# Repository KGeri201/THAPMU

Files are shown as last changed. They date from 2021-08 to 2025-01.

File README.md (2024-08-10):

<p align="center"></P>

# THAPMU
THAPMU stands for **T**emerature, **H**umiditity and **A**ir **P**ressure **M**easurement **U**nit. 

## Story
I wanted to create a small, cheap and easy to make IoT sensor, that works with nearly anything,  
to monitor the temerapture and humidity levels of multiple rooms.

## Hardware
The custom PCB is a very simple power adapter to power and connect the sensor and the ESP.

## Software
It uses [ESPHome](https://esphome.io/index.html), [MQTT](https://de.wikipedia.org/wiki/MQTT), [InfluxDB](https://www.influxdata.com/) and a [script](MQTTInfluxDBBridge.py) to connect all this together.  
I found a [code](https://randomnerdtutorials.com/esp8266-nodemcu-mqtt-publish-bme280-arduino/) very similar and nearly perfect for my use.  
I only modified it a little to make it a perfect fit.    
It uses Grafana to visualize the data, but anything else can be used.

## Installation
### Docker (recomended)
Follow the Guide for [docker deployment](DOCKER.md)

### Manual
Download the thapmu.sh with wget or any other way.
```sh
wget https://raw.githubusercontent.com/KGeri201/THAPMU/main/thapmu.sh
```
And execute it as sudo
```sh
sudo ./thapmu.sh
```
#### Step by step
Grafana will be added to apt sources.  
All the needed packages will be installed  
```sh
apt-get install -y influxdb influxdb-client mosquitto mosquitto-clients python3 python3-pip grafana-enterprise
```
All the neded files will be downloaded.
```sh
wget -q -O /tmp/requirements.txt https://raw.githubusercontent.com/KGeri201/THAPMU/main/requirements.txt
wget -q -O MQTTInfluxDBBridge.py https://raw.githubusercontent.com/KGeri201/THAPMU/main/MQTTInfluxDBBridge.py
wget -q -O /etc/systemd/system/mqttinfluxdbbridge.service https://raw.githubusercontent.com/KGeri201/THAPMU/main/mqttinfluxdbbridge.service
```
Additional config will be added to mosquitto  
```sh
echo "listener 1883" > /etc/mosquitto/conf.d/allow.conf && echo "allow_anonymous true" >> /etc/mosquitto/conf.d/allow.conf
```
Python libraries will also be installed  
```sh
pip3 -q install -r /tmp/requirements.txt
```
Database will be set up, and services will be started
```sh
systemctl start mqttinfluxdbbridge
systemctl start grafana-server
systemctl restart influxdb
systemctl start mosquitto
```
Additionaly you can also enable all the services to start automatically after starting the device  
```sh
systemctl enable mosquitto
systemctl enable influxdb
systemctl enable grafana-server
systemctl enable mqttinfluxdbbridge
```

## Sensor
### Requirements
* 1 THAPMU board (fully fitted, and ready to use)
* 1 ESP01 breakout board
* 1 BME or BMP sensor
* an extra external serial adapter to flash your ESP
* an USB-C cable to power the board.

### Instructions
#### ESPHome
1. Install ESPHome on a server.
2. Go to http://ip-of-your-server:6052
3. Add new device.
4. Load the [example_esphome.conf](example_esphome.conf) and edit the values to fit your needs.  
   Make sure that the right sensor is selected and all the credentials are right.
5. Flash the code to the ESP following the guide from ESPHome

#### Legacy
1. Open the code for the ESP and change the library according to your sensor.  
```ino
#include <Adafruit_BME280.h>

// Sensor I2C
Adafruit_BME280 sensor;
```
2. Fill in your WLAN SSID and password, and the address of the MQTT broker.  
   If your MQTT broker needs credentials to authenticate, set them.  
   Also add the location and the name of the device.
```ino
#define NAME "NAME_OF_THE_DEVICE"
#define LOCATION "LOCATION_OF_THE_DEVICE"
#define WIFI_SSID "REPLACE_WITH_YOUR_SSID"
#define WIFI_PASSWORD "REPLACE_WITH_YOUR_PASSWORD"

// Raspberri Pi Mosquitto MQTT Broker
#define MQTT_HOST IPAddress(X, X, X, X)
// For a cloud MQTT broker, type the domain name
//#define MQTT_HOST "example.com"
#define MQTT_PORT 1883
// If your MQTT broker requires authentication, set them below
#define MQTT_USER ""
#define MQTT_PASSWORD ""
``` 
3. Flash the ESP.  
4. Plug the board in somewhere and wait for it to connect to your WLAN and to the Server, which you previously set up (decribed under [Installation](https://github.com/KGeri201/THAPMU#installation)).
5. Go to the [Grafana](https://grafana.com/) site, hosted on your server http://ip-of-your-server:3000 and login with the default credentials.
6. Under the Configurations add the [InfluxDB](https://www.influxdata.com/products/influxdb-overview/) data source.  
  Fill in the name of the database, user and password.  
  These you have set during the setup process.
7. Make a new dashboard with the newly added InfluxDB datasource and choose the measurement.  
There are three topics:  
   - THAPMU/**LOCATION**/**NAME**/sensor/temperature/state   
   - THAPMU/**LOCATION**/**NAME**/sensor/humidity/state
   - THAPMU/**LOCATION**/**NAME**/sensor/pressure/state
8. You are up and running.  

## Credits
[HimbeersaftLP](https://github.com/HimbeersaftLP)  
[KGeri201](https://github.com/KGeri201)  

## License
[Apache License 2.0](LICENSE)

## Project status
Ready to deploy.

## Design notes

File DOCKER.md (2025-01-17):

# THAPMU

Guide to deploy project as a docker container.  
To run the container, MQTT and InfluxDB are required.
To visuallize the data we use grafana.

## Docker Compose
```yml
version: '3.3'
services:
  mqtt:
    container_name: mosquitto
    restart: unless-stopped
    ports:
      - 1883:1883
    volumes:
      - ./mosquitto:/mosquitto/config
    image: eclipse-mosquitto:latest

  db:
    container_name: influxdb
    restart: unless-stopped
    environment:
      - DOCKER_INFLUXDB_INIT_MODE=setup
      - DOCKER_INFLUXDB_INIT_USERNAME=db_user
      - DOCKER_INFLUXDB_INIT_PASSWORD=db_pwd_123
      - DOCKER_INFLUXDB_INIT_ORG=thapmu
      - DOCKER_INFLUXDB_INIT_BUCKET=thapmu
      - DOCKER_INFLUXDB_INIT_ADMIN_TOKEN=my-super-secret-auth-token
    volumes:
      - ./influxdb2:/var/lib/influxdb2
    image: influxdb:latest

  grafana:
    container_name: grafana
    restart: unless-stopped
    ports:
      - 3000:3000
    volumes:
      - grafana_data:/var/lib/grafana
    image: grafana/grafana:latest

  thapmu:
    container_name: thapmu
    restart: unless-stopped
    environment:
      - INFLUXDB_ORG=thapmu
      - INFLUXDB_BUCKET=thapmu
      - INFLUXDB_TOKEN=my-super-secret-auth-token
    depends_on:
      - mqtt
      - db
    image: ghcr.io/kgeri201/thapmu:latest

volumes:
  grafana_data: {}
```

## Installation
1. Install docker compose.  
2. Dowload the docker-compose.yml and edit it.
```sh
wget https://raw.githubusercontent.com/KGeri201/THAPMU/main/docker-compose.yml
```
Make sure to set all the necessary environment variables.
| Variable | Description | Default Value |
|---|---|---|
| INFLUXDB_ADDRESS | The address of the Influxdb database. (Optional) | "db" |
| INFLUXDB_ORG | The name to set for the system's initial organization. |"thapmu" |
| INFLUXDB_BUCKET | The name to set for the system's initial bucket. | "thapmu" |
| INFLUXDB_TOKEN | The authentication token to associate with the system's initial super-user. | "my-super-secret-auth-token" |
| INFLUXDB_PORT | The port influxdb listens on. (Optional) | 8086 |
| MQTT_ADDRESS | The address of the Influxdb database. (Optional) | "mqtt" |
| MQTT_PORT | The port the mqtt broker listens on. (Optional) | 1883 |
| MQTT_USER | MQTT user. (Optional) | "" |
| MQTT_PASSWORD | MQTT password. (Optional) | "" |
| MQTT_TOPIC | The MQTT Topic. (Optional) | "THAPMU/+/+/sensor/+/state" |
| MQTT_REGEX | Regex to match the MQTT Topic. (Optional) | "THAPMU/([^/]+)/([^/]+)/sensor/([^/]+)/state" |
| MQTT_CLIENT_ID | ID of the MQTT Client (Optional) | "MQTTInfluxDBBridge" |
<!--- | INFLUXDB_USER | The username to set for the system's initial super-user. (Optional) | "db_user" | --->
<!--- | INFLUXDB_PASSWORD | The password to set for the system's inital super-user. (Optional) | "db_pwd_123" | --->
<!--- | INFLUXDB_DATABASE |The name to set for the system's initial database. (Optional) | "thapmu" | --->

3. Create config file ```mosquitto.conf``` inside the directory mounted inside the mosquitto container.
```conf
listener 1883
allow_anonymous true
```

4. Start all containers
```sh
docker compose up -d
```

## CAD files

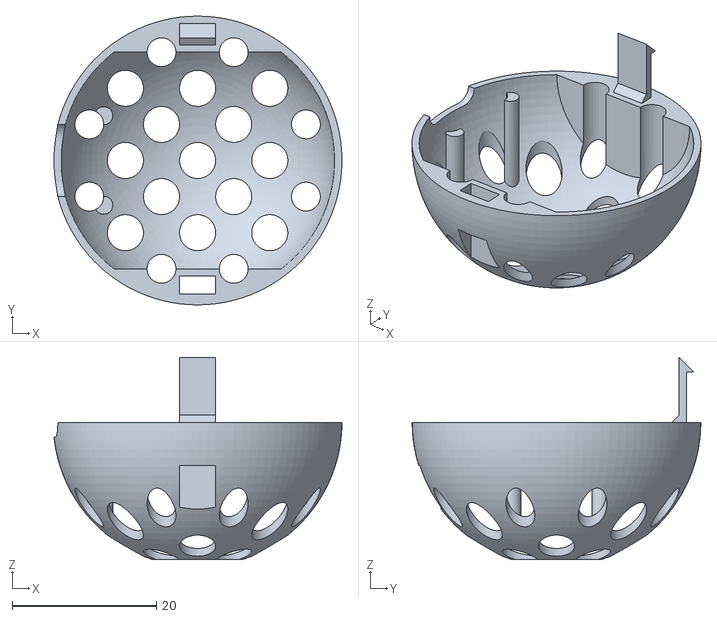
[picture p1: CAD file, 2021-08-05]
THAPMU.stl
39.9 x 40.0 x 28.0

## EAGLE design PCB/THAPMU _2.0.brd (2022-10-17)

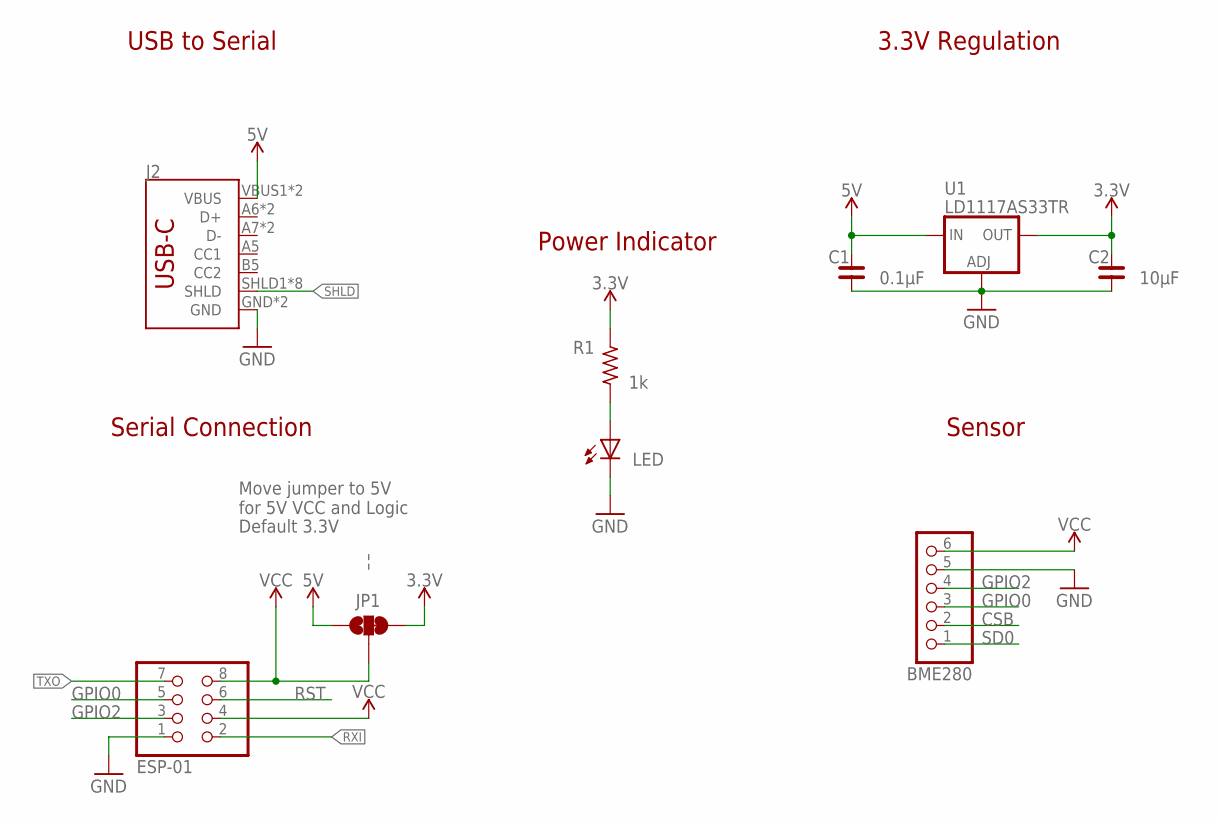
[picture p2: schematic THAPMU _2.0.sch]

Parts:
BME280: PINHD-1X6; 1X06
C1: 0.1µF; C1206
C2: 10µF; C1206
ESP-01: PINHD-2X4; 2X04
J2: USB_C16PIN; USB-C-16P
JP1: JUMPER-SMT_3_1-NC_TRACE_SILK; SMT-JUMPER_3_1-NC_TRACE_SILK
LED: LEDSMT1206; 1206
R1: 1k; R1206
U1: LD1117AS33TR; SOT223

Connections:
3.3V: C2.2, JP1.3, R1.2, U1.4 (OUT)
5V: C1.2, J2.VBUS1 (VBUS), J2.VBUS2 (VBUS), JP1.1, U1.3 (IN)
CSB: BME280.2
GND: BME280.5, C1.1, C2.1, ESP-01.1, J2.GND, J2.GND2 (GND), LED.C, U1.1 (ADJ)
GPIO0: BME280.3, ESP-01.5
GPIO2: BME280.4, ESP-01.3
unnamed: LED.A, R1.1
RST: ESP-01.6
RXI: ESP-01.2
SD0: BME280.1
SHLD: J2.SHLD1 (SHLD), J2.SHLD2 (SHLD), J2.SHLD3 (SHLD), J2.SHLD4 (SHLD), J2.SHLD5 (SHLD), J2.SHLD6 (SHLD), J2.SHLD7 (SHLD), J2.SHLD8 (SHLD)
TXO: ESP-01.7
VCC: BME280.6, ESP-01.4, ESP-01.8, JP1.2

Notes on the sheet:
Default 3.3V
USB to Serial
3.3V Regulation
Move jumper to 5V for 5V VCC and Logic
Serial Connection
Sensor
Power Indicator

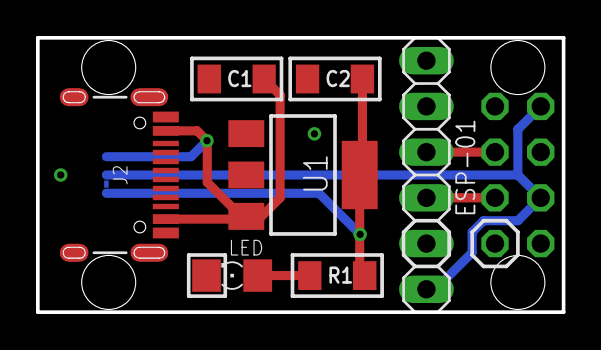
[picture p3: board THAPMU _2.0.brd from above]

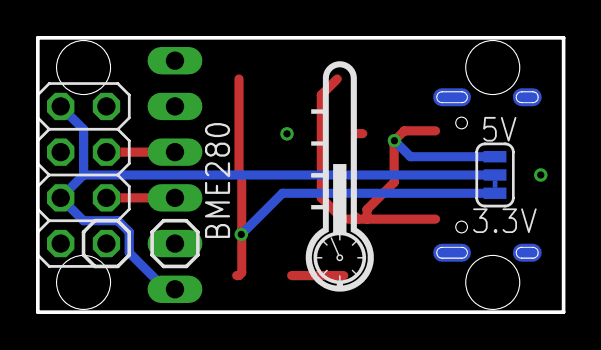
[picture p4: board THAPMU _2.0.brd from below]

Board: 2 copper layers, 29.2 x 15.2 mm, 10 parts (2 on the bottom side), 8 nets.

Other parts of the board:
LOGO: THAPMU

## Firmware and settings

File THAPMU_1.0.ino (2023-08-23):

/*
  Original at https://RandomNerdTutorials.com/esp8266-nodemcu-mqtt-publish-bme280-arduino/
  
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
  The above copyright notice and this permission notice shall be included in all
  copies or substantial portions of the Software.
*/

#include <Wire.h>
#include <Adafruit_Sensor.h>
#include <ESP8266WiFi.h>
#include <Ticker.h>
#include <AsyncMqttClient.h>
#include <Adafruit_BME280.h>

// Sensor I2C
Adafruit_BME280 sensor;

#define NAME "NAME_OF_THE_DEVICE"
#define LOCATION "LOCATION_OF_THE_DEVICE"
#define WIFI_SSID "REPLACE_WITH_YOUR_SSID"
#define WIFI_PASSWORD "REPLACE_WITH_YOUR_PASSWORD"

// Raspberri Pi Mosquitto MQTT Broker
#define MQTT_HOST IPAddress(X, X, X, X)
// For a cloud MQTT broker, type the domain name
//#define MQTT_HOST "example.com"
#define MQTT_PORT 1883
// If your MQTT broker requires authentication, set them below
#define MQTT_USER ""
#define MQTT_PASSWORD ""

/*----------------------------------------------------------------------------------------------------------------------*/

// Interval of topic updates in seconds
#define Interval 10

// Value, which will be substracted from the Temperature, due to the sensor heating itself
const double tempErrorMargin = 5.5;

// Temperature MQTT Topics
const String MQTT_PUB_TEMP = "THAPMU/" + String(LOCATION) + "/" + String(NAME)+ "sensor/temperature/state";
const String MQTT_PUB_HUM = "THAPMU/" + String(LOCATION) + "/" + String(NAME) + "sensor/humidity/state";
const String MQTT_PUB_PRES = "THAPMU/" + String(LOCATION) + "/" + String(NAME) + "sensor/pressure/state";

AsyncMqttClient mqttClient;
Ticker mqttReconnectTimer;

WiFiEventHandler wifiConnectHandler;
WiFiEventHandler wifiDisconnectHandler;
Ticker wifiReconnectTimer;

unsigned long previousMillis = 0;   // Stores last time temperature was published
const long interval = 10000;        // Interval at which to publish sensor readings

void connectToWifi() {
  Serial.println("Connecting to Wi-Fi...");
  WiFi.begin(WIFI_SSID, WIFI_PASSWORD);
}

void onWifiConnect(const WiFiEventStationModeGotIP& event) {
  Serial.println("Connected to Wi-Fi.");
  connectToMqtt();
}

void onWifiDisconnect(const WiFiEventStationModeDisconnected& event) {
  Serial.println("Disconnected from Wi-Fi.");
  mqttReconnectTimer.detach(); // ensure we don't reconnect to MQTT while reconnecting to Wi-Fi
  wifiReconnectTimer.once(2, connectToWifi);
}

void connectToMqtt() {
  Serial.println("Connecting to MQTT...");
  mqttClient.connect();
}

void onMqttConnect(bool sessionPresent) {
  Serial.println("Connected to MQTT.");
  Serial.print("Session present: ");
  Serial.println(sessionPresent);
}

void onMqttDisconnect(AsyncMqttClientDisconnectReason reason) {
  Serial.println("Disconnected from MQTT.");

  if (WiFi.isConnected()) {
    mqttReconnectTimer.once(2, connectToMqtt);
  }
}

/*void onMqttSubscribe(uint16_t packetId, uint8_t qos) {
  Serial.println("Subscribe acknowledged.");
  Serial.print("  packetId: ");
  Serial.println(packetId);
  Serial.print("  qos: ");
  Serial.println(qos);
}

void onMqttUnsubscribe(uint16_t packetId) {
  Serial.println("Unsubscribe acknowledged.");
  Serial.print("  packetId: ");
  Serial.println(packetId);
}

void onMqttPublish(uint16_t packetId) {
  Serial.print("Publish acknowledged.");
  Serial.print("  packetId: ");
  Serial.println(packetId);
}*/

void setup() {
  Serial.begin(115200);
  Serial.println();
  
  Wire.pins(0, 2);
  Wire.begin();
  
  // Initialize sensor 
  if (!sensor.begin(0x76)) {
    Serial.println("Could not find a valid sensor, check wiring!");
    while (1);
  }
  
  wifiConnectHandler = WiFi.onStationModeGotIP(onWifiConnect);
  wifiDisconnectHandler = WiFi.onStationModeDisconnected(onWifiDisconnect);

  mqttClient.onConnect(onMqttConnect);
  mqttClient.onDisconnect(onMqttDisconnect);
  //mqttClient.onSubscribe(onMqttSubscribe);
  //mqttClient.onUnsubscribe(onMqttUnsubscribe);
  //mqttClient.onPublish(onMqttPublish);
  mqttClient.setServer(MQTT_HOST, MQTT_PORT);
  // If your broker requires authentication (username and password), set them below
  if (String(MQTT_USER).length() > 0 && String(MQTT_PASSWORD).length() > 0) {
    mqttClient.setCredentials(MQTT_USER, MQTT_PASSWORD);
  }
  
  connectToWifi();
}

void loop() {
  // Publish an MQTT message on topic esp/sensor/temperature
  uint16_t packetIdPub1 = mqttClient.publish(MQTT_PUB_TEMP.c_str(), 1, true, String(sensor.readTemperature()  - tempErrorMargin).c_str()); //temp = 1.8*sensor.readTemperature() + 32                        
  Serial.printf("Publishing on topic %s at QoS 1, packetId: %i ", MQTT_PUB_TEMP, packetIdPub1);

  // Publish an MQTT message on topic esp/sensor/humidity
  uint16_t packetIdPub2 = mqttClient.publish(MQTT_PUB_HUM.c_str(), 1, true, String(sensor.readHumidity()).c_str());                            
  Serial.printf("Publishing on topic %s at QoS 1, packetId: %i ", MQTT_PUB_HUM, packetIdPub2);

  // Publish an MQTT message on topic esp/sensor/pressure
  uint16_t packetIdPub3 = mqttClient.publish(MQTT_PUB_PRES.c_str(), 1, true, String(sensor.readPressure()/100.0F).c_str());                            
  Serial.printf("Publishing on topic %s at QoS 1, packetId: %i ", MQTT_PUB_PRES, packetIdPub3);
  
  // wait before reading te sensors again
  delay(Interval *1000);
}

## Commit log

2021-07-20 Rename ThermoAndHumidityMeter _1.0.brd to THAPMU _1.0.brd
    [THAPMU _1.0.brd]
2021-07-20 Rename ThermoAndHumidityMeter _1.0.sch to THAPMU _1.0.sch
    [THAPMU _1.0.sch]
2021-07-20 Rename Simple version/THAPMU _1.0.brd to Version with Serial Adapter/THAPMU _1.0.brd
    [THAPMU _1.0.brd]
2021-07-20 Rename Simple version/THAPMU _1.0.sch to Version with Serial Adapter/THAPMU _1.0.sch
    [THAPMU _1.0.sch]
2021-07-20 Rename Version with serial adapter/THAPMU _1.0.brd to Simple Version/THAPMU _1.0.brd
    [THAPMU _1.0.brd]
2021-07-20 Rename Version with serial adapter/THAPMU _1.0.sch to Simple Version/THAPMU _1.0.sch
    [THAPMU _1.0.sch]
2022-09-29 Rename THAPMU _1.0.brd to THAPMU _2.0.brd
    [THAPMU _2.0.brd]
2022-09-29 Rename THAPMU _1.0.sch to THAPMU _2.0.sch
    [THAPMU _2.0.sch]
2022-10-17 minor fixes
    [THAPMU _1.0.brd, THAPMU _1.0.sch, THAPMU _2.0.brd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]
2023-08-31 cleaned up docker
    [THAPMU _1.0.brd, THAPMU _1.0.sch, THAPMU _2.0.brd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]

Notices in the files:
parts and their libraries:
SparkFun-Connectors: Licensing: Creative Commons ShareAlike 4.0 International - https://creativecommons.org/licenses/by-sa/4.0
